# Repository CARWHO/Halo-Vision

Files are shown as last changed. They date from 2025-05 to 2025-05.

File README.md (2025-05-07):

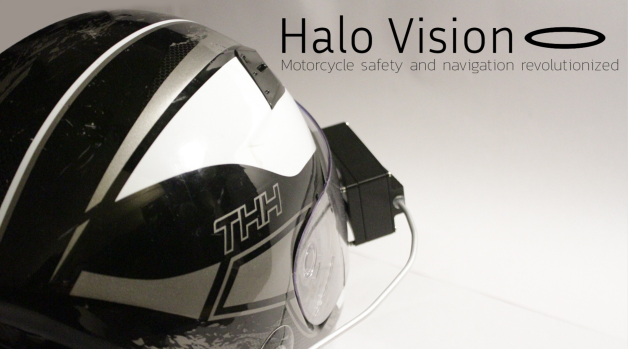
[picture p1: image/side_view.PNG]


# Halo Vision

**Open-Source Heads-Up Display for Motorcycle Safety**

Halo Vision is a helmet-mounted HUD that delivers turn-by-turn navigation and indicator notifications to motorcyclists, hands-free. Inspired by personal experiences, it evolved from a simple indicator broadcaster into a full display system with custom PCBs and a companion mobile app.

A full report—including detailed design motivations, hardware walkthrough, and CFD analysis—is available at:  
https://www.kahuhutton.com/work/halo-vision

---

## 🚀 What’s in this Repo

- **Schematics**    
  See [`/schematics/README.md`](schematics/schematics_readme.md).  
  Organized by module under `/schematics/`:
  - **Brain Module** and **Display Module** each have a `Project Outputs/` folder containing:  
    - **3D Views**  
    - **BOM (JLCPCB)**  
    - **Gerber**  
    - **JLCPCB Quotation**  
    - **Pick and Place**  
    - **Schematic** (PDF/PNG)  
    - **STEP** files  
    - **Source Files** (KiCad/Eagle project)  
    - **Original sketches**  
  These folders include all fabrication data and documentation for both the Brain and Display modules.    
  - ATmega32U2 pin mapping and net labels for easy modification  
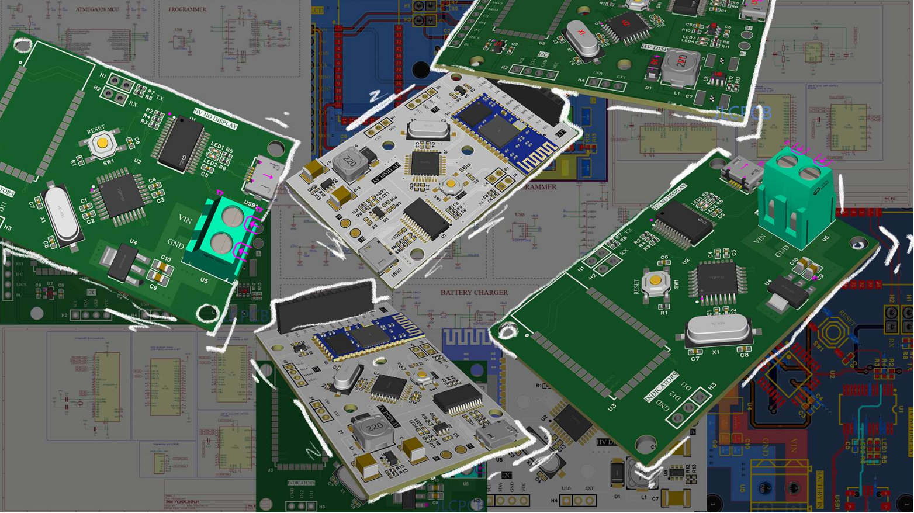
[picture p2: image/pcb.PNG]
  

- **Software**  
  See [`/software/README.md`](software/software_readme.md).  
  Organized under `/software/`:
  - **firmware/**
    - **brain_module/**  
      - `Makefile`  
      - `include/`  
        - `config.h`  
        - **hal/**: `gpio.h`, `uart.h`, `i2c.h`  
        - **modules/**: `gps.h`, `ble_uart.h`, `battery.h`  
      - `src/`  
        - `main.c`  
        - **hal/**: `gpio.c`, `uart.c`, `i2c.c`  
        - **drivers/**: `gps_driver.c`, `ble_uart.c`, `battery_monitor.c`  
        - **modules/**: `nav_logic.c`, `signal_detector.c`  
        - **util/**: `ring_buffer.c`, `logger.c`  
    - **display_module/**  
      - `Makefile`  
      - `include/`  
        - `config.h`  
        - **hal/**: `gpio.h`, `spi.h`, `uart.h`  
        - **modules/**: `display_driver.h`, `ble_rx.h`  
      - `src/`  
        - `main.c`  
        - **hal/**: `gpio.c`, `spi.c`, `uart.c`  
        - **drivers/**: `lcd_driver.c`, `ble_rx.c`  
        - **modules/**: `screen_updater.c`, `battery_status.c`  
        - **util/**: `ring_buffer.c`, `logger.c`  
  - **host_tools/**  
    - `flash_firmware.py`  
    - `diagnostics.py`  
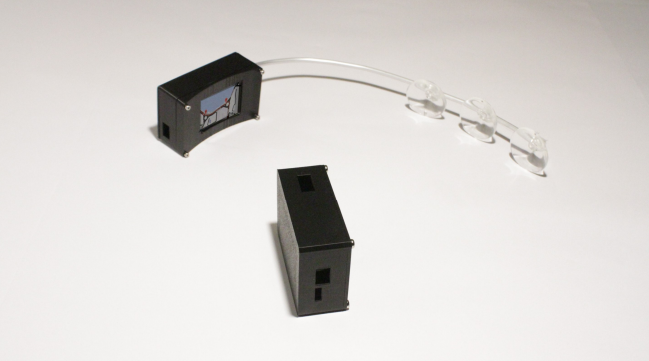
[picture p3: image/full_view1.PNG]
Software in action
  

## CAD Models & 3D Prints

All CAD assets live under the `/cad/` folder, organized by module. Each sub-folder includes a SolidWorks assembly (`.SLDASM`) plus its corresponding part files (`.SLDPRT`).  

**Module folders:**  
- `brainmodule/` – electronics housing assemblies and parts  
- `displaymodule/` – display housing assemblies and parts  
- `misc/` – hardware components (bolts, spacers, etc.)  

**Mount options:**  
- **HaloMount** – bracketed mount for helmet rim installation  
- **Direct Mount** – low-profile mount for direct shell attachment  

For print parameters, materials, and recommended hardware, see [`/cad/print_settings.md`](cad/print_settings.md).  
 
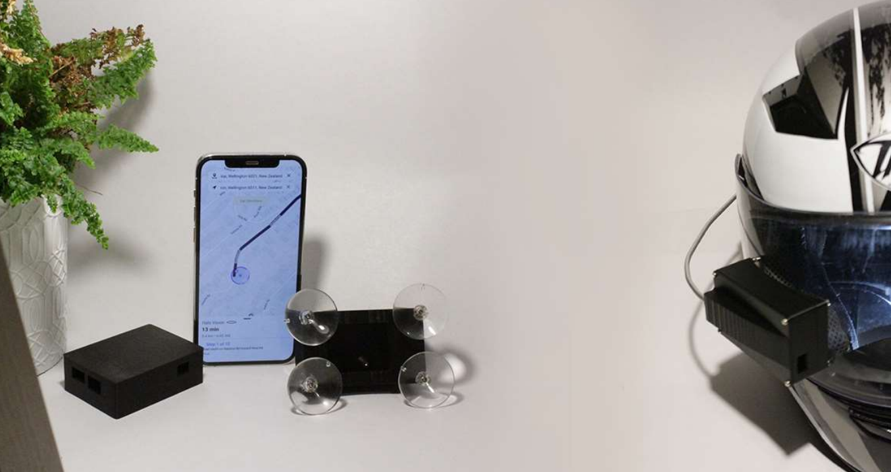
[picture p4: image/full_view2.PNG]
CAD models and mounts
  

- **Mobile App**  
  See [`/app/README.md`](app/README.md).  
  Joel Bannister’s Android navigator app threads GPS data to the HUD over Bluetooth:  
  https://github.com/1ceseismic/android_mapbox_lcd_navigator  
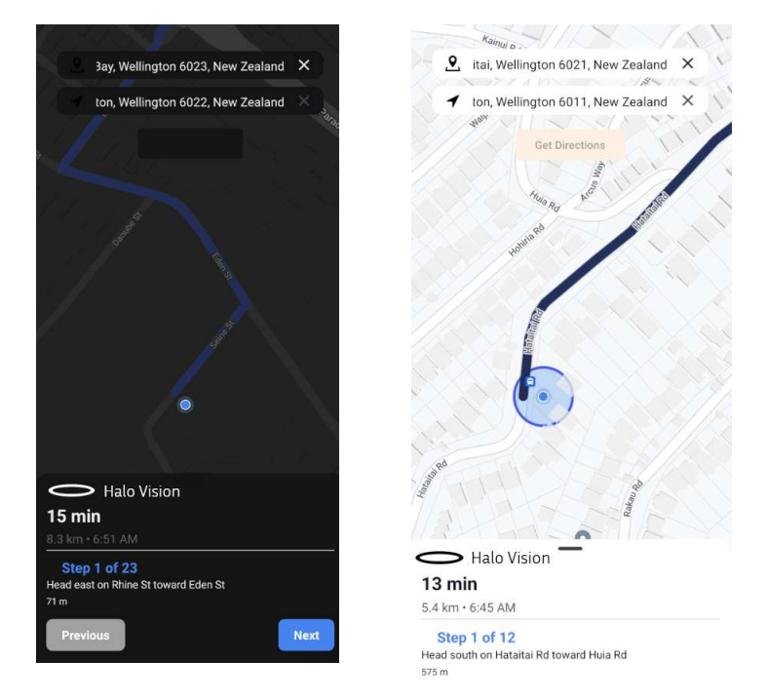
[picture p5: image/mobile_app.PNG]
Mobile App
  

---

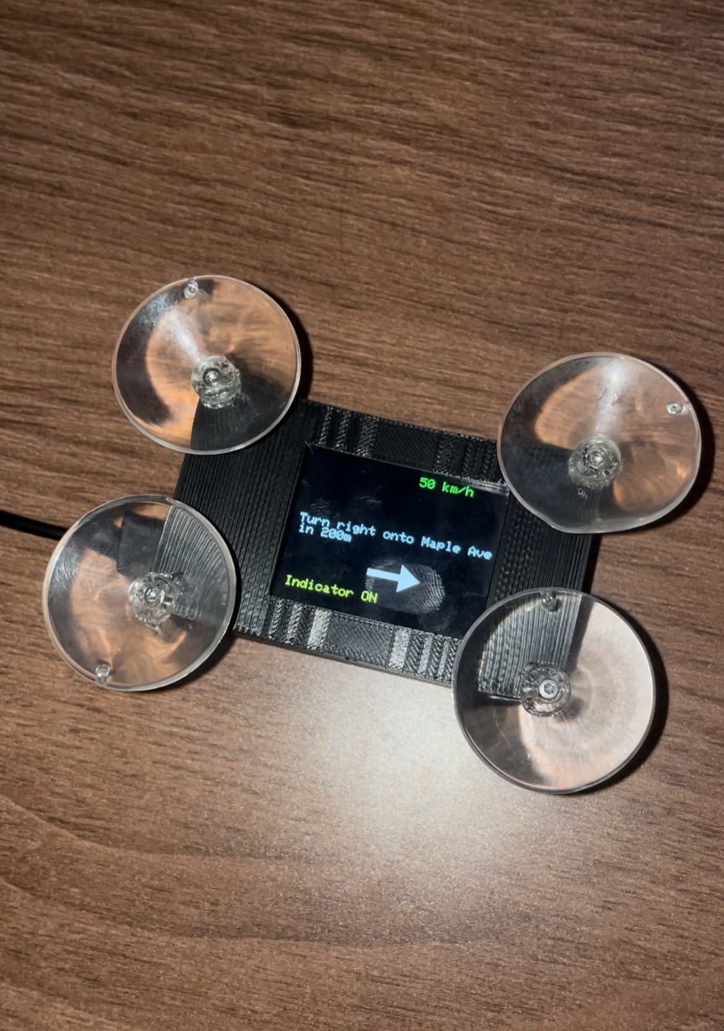
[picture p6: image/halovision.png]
Halo Vision Demo
  
## 🏁 Getting Started

Follow these steps to take your Halo Vision from GitHub to helmet-mounted HUD:

### 1. Clone this repo
```bash
git clone https://github.com/YourUsername/HaloVision.git
cd HaloVision
```

### 2. Order PCBs
- Open `/schematics/brain_module/Project Outputs/BOM (JLCPCB)/BOM.csv` and `/schematics/display_module/Project Outputs/BOM (JLCPCB)/BOM.csv`
- Upload both CSVs to JLCPCB (or your favorite board house) to fabricate the Brain and Display modules

### 3. 3D-print mounts & housings
- Choose a mount style (HaloMount, Direct Mount, etc.) in `/cad/`
- Follow `/cad/print_settings.md` for filament type, layer height, infill, and recommended screws

### 4. Build & flash firmware

**Brain Module:**
```bash
cd software/firmware/brain_module
make all
make flash
```

**Display Module:**
```bash
cd ../../display_module
make all
make flash
```

### 5. Install the mobile app
```bash
git clone https://github.com/1ceseismic/android_mapbox_lcd_navigator.git
```
Import into Android Studio, configure your Mapbox token, then build & install the APK on your device.

### 6. Assemble & power up
- Populate each PCB with the ordered components and solder per the assembly drawings
- Mount the PCBs in your 3D-printed housings and secure with the recommended screws
- Connect a Li-Po battery to each module's power header

### 7. Pair & test
- On your phone, open the installed app and pair to the HaloVisionHUD (PIN: 1234)
- Turn on the Brain Module (bike) and Display Module (helmet)
- Verify GPS lock, turn-signal detection, and live HUD updates before your next ride

---

Now you're ready to ride with Halo Vision. Enjoy hands-free navigation and stay safe!

📄 License
Distributed under the MIT License. See LICENSE for details.

Email me for further edits: kahu@kora.ac

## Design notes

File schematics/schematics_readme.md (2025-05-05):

# Schematics Overview

This document explains the functional blocks of the schematic diagrams for both the **Brain Module** (bike-mounted) and the **Display Module** (helmet-mounted).

---

## Brain Module Schematic

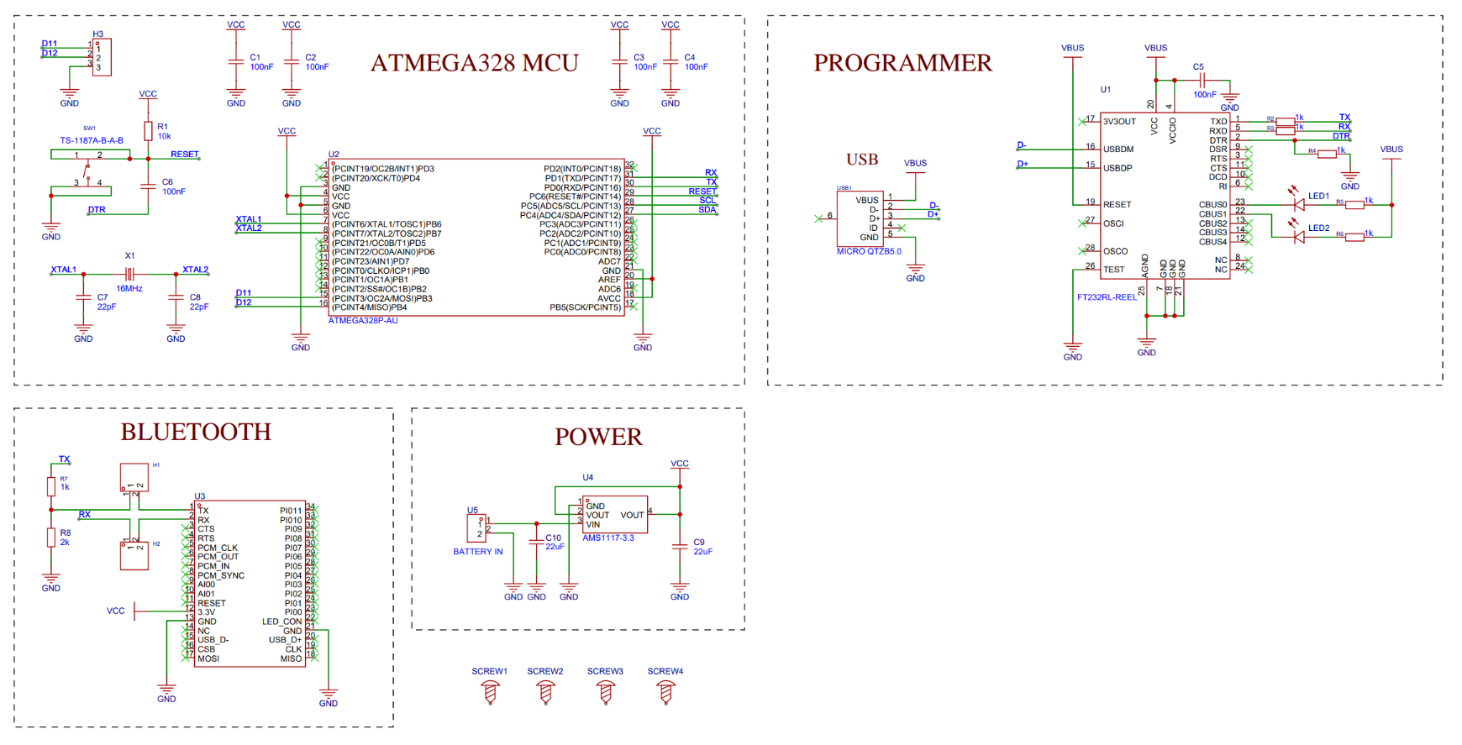
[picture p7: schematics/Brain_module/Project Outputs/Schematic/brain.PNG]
Brain Module Schematic


1. **ATmega328 MCU**  
   - **U2**: ATMEGA328P-AU microcontroller  
   - **Clock**: 16 MHz crystal (X1) with load caps C7/C8  
   - **Decoupling**: C1–C4 (100 nF) on VCC/AVCC  
   - **Reset circuit**: R1 (10 kΩ pull-up) + C6 (100 nF), DTR line via SW1 for auto-reset  

2. **Programmer Interface**  
   - **U1**: FT232RL USB-to-UART bridge  
   - **Connector**: MICRO QTZB5.0 (VBUS, D+, D–, ID, GND)  
   - **Signals**: TXD/RXD ↔ MCU PD0/PD1, DTR ↔ reset  
   - **Indicators**: LED1/LED2 with R5/R6 (1 kΩ) for TX/RX activity  

3. **Bluetooth Interface**  
   - **U3**: Bluetooth module (PI0xx)  
   - **Level shifting**: R7 (1 kΩ) on TX, R8 (2 kΩ) on RX  
   - **Connections**: TX/RX, CTS/RTS to MCU; powered from 3.3 V rail  

4. **Power Regulation**  
   - **U5**: AMS1117-3.3 linear regulator  
   - **Input cap**: C10 (22 µF), **Output cap**: C9 (22 µF)  
   - **Battery input**: VBAT → VIN  

5. **Mechanical Mounts**  
   - **Screw footprints**: SCREW1–SCREW4 for enclosure attachment  

---

## Display Module Schematic

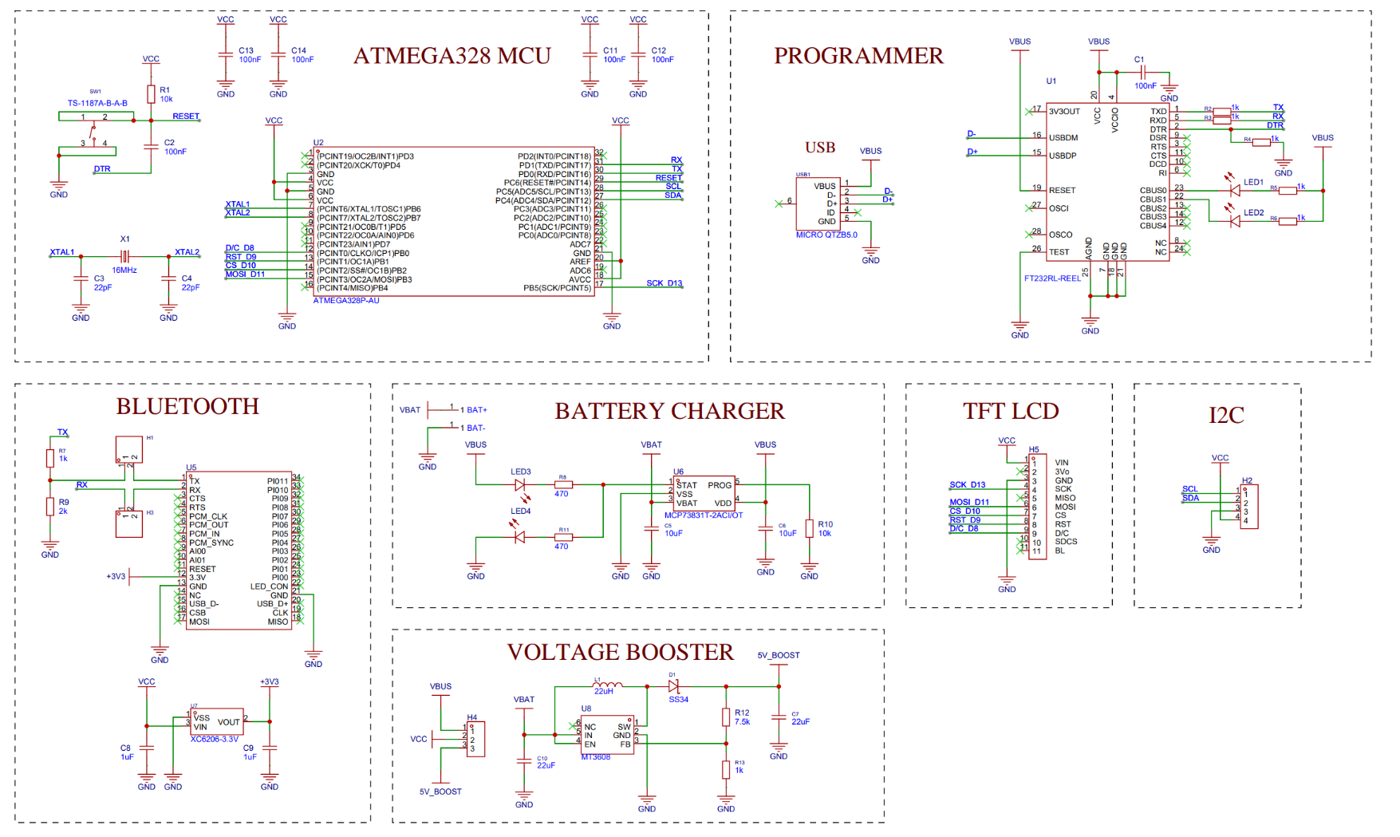
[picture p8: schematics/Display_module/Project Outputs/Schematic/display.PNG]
Display Module Schematic


1. **ATmega328 MCU**  
   - **U2**: ATMEGA328P-AU, identical clock & reset circuitry to Brain Module  

2. **Programmer Interface**  
   - **U1**: FT232RL, same USB-to-UART connections for firmware flashing  

3. **Bluetooth Receiver**  
   - **U5**: Bluetooth module wired for BLE RX only  

4. **Battery Charger**  
   - **U6**: MCP73831 Li-ion charger  
   - **Status LEDs**: LED3/LED4 with R8/R11 (470 Ω)  
   - **Input**: VBUS, **Output**: VBAT  

5. **TFT LCD Interface**  
   - **H5 header**:  
     - SCK (D13), MOSI (D11), MISO, CS (D10)  
     - RST (D8), D/C, SDCS, BL (backlight)  

6. **I²C Expansion**  
   - **H2 header**: SCL, SDA for external sensors  

7. **Voltage Booster**  
   - **U8**: MT3608 boost converter  
   - **Feedback**: R12 (7.5 kΩ), R13 (1 kΩ) → 5V_BOOST  
   - **Input cap**: C10 (22 µF), **Output cap**: C7 (22 µF)  

---

**All source files** (`.kicad_sch`, `.kicad_pcb`), Gerbers, BOM, Pick-and-Place, and STEP exports live under each module’s **Project Outputs/** folder.

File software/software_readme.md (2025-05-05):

# Halo Vision Software

This directory contains the software components for the Halo Vision project.

## Firmware

The `firmware/` directory holds the embedded software for the two main hardware modules:

- **`firmware/brain_module/`**: Firmware for the main processing unit. This module handles GPS data parsing, navigation logic, sensor reading (turn signals, speed, battery), and BLE communication with the Display Module. It runs on an ATmega328P microcontroller.

- **`firmware/display_module/`**: Firmware for the helmet-mounted display unit. This module receives data from the Brain Module via BLE, manages the LCD display, monitors its own battery and charging status, and renders the user interface. It also runs on an ATmega328P microcontroller.

Each firmware directory contains:
    - `include/`: Header files (.h) defining interfaces and configurations.
    - `src/`: Source code files (.c) implementing the firmware logic, drivers, and HAL.
    - `Makefile`: Build script for compiling the firmware using `avr-gcc`.

## Host Tools

The `host_tools/` directory contains utility scripts for development and maintenance:

- **`flash_firmware.py`**: (Placeholder) Script for flashing compiled firmware onto the microcontrollers.
- **`diagnostics.py`**: (Placeholder) Script for running diagnostics or communicating with the modules for debugging.

## Building Firmware

Navigate to either the `firmware/brain_module` or `firmware/display_module` directory and use the provided `Makefile`. Requires the `avr-gcc` toolchain and `avrdude` (for flashing).

```bash
# Example for Brain Module
cd firmware/brain_module
make all  # Compile the firmware
make flash # Flash the firmware (requires programmer configuration in Makefile)
make clean # Remove build artifacts
```

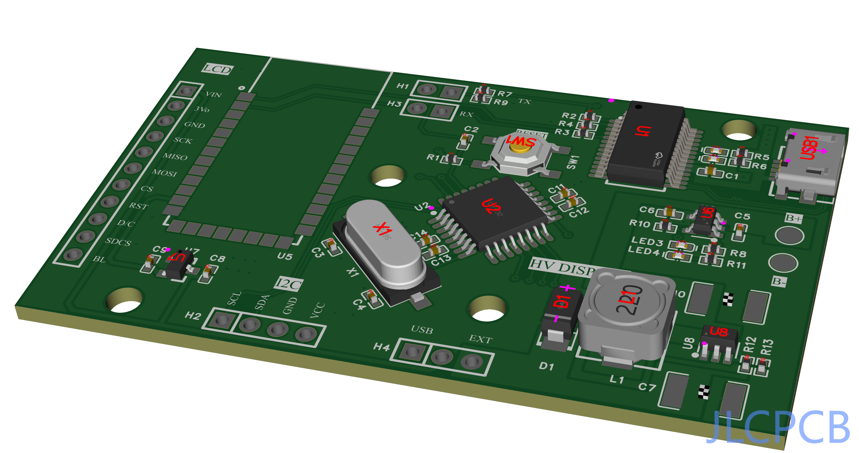
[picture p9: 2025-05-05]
schematics/Display_module/Project Outputs/3D Views/capture-2024-06-08T05_45_36.513Z.png

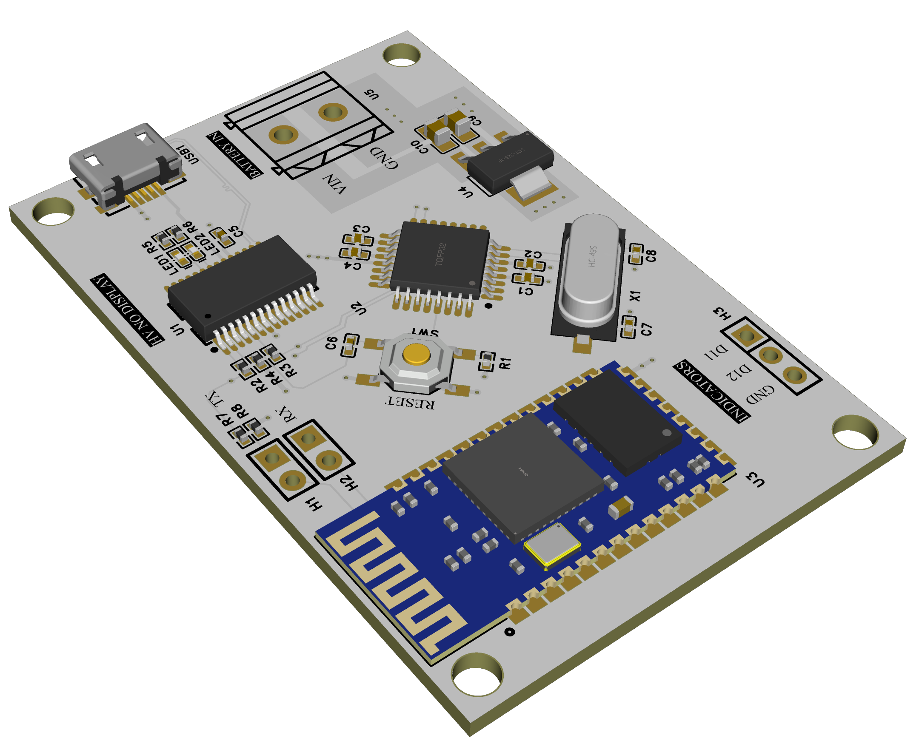
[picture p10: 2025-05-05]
schematics/Brain_module/Project Outputs/3D View/3D_PCB_2024-06-09_S3.png

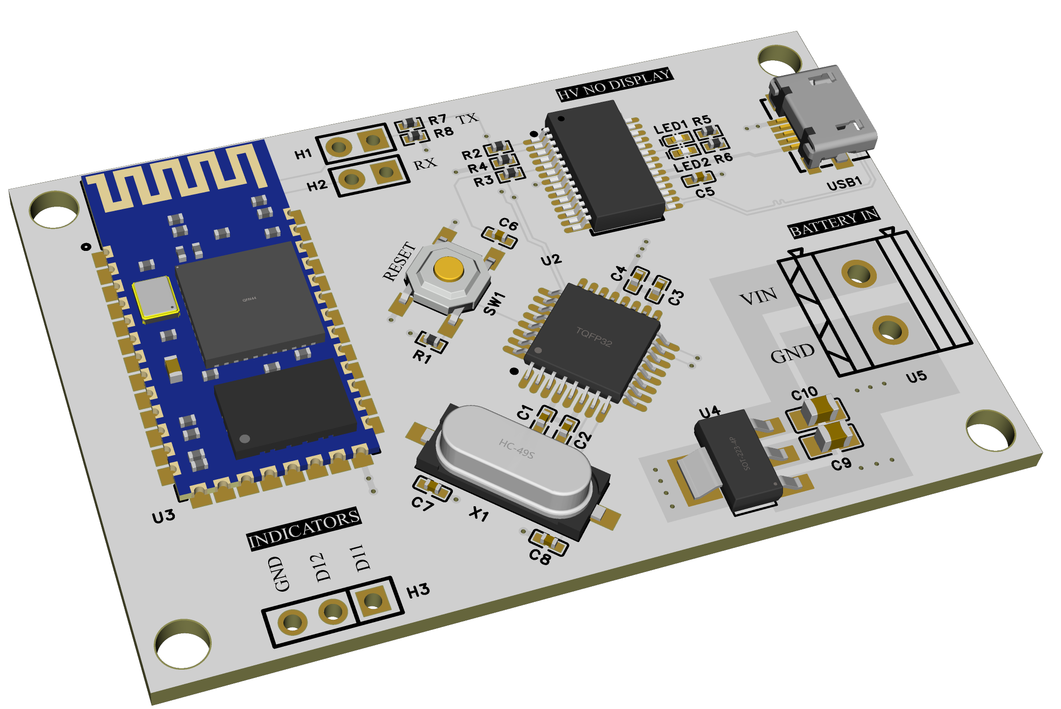
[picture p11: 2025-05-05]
schematics/Brain_module/Project Outputs/3D View/3D_PCB_2024-06-09_S1.png

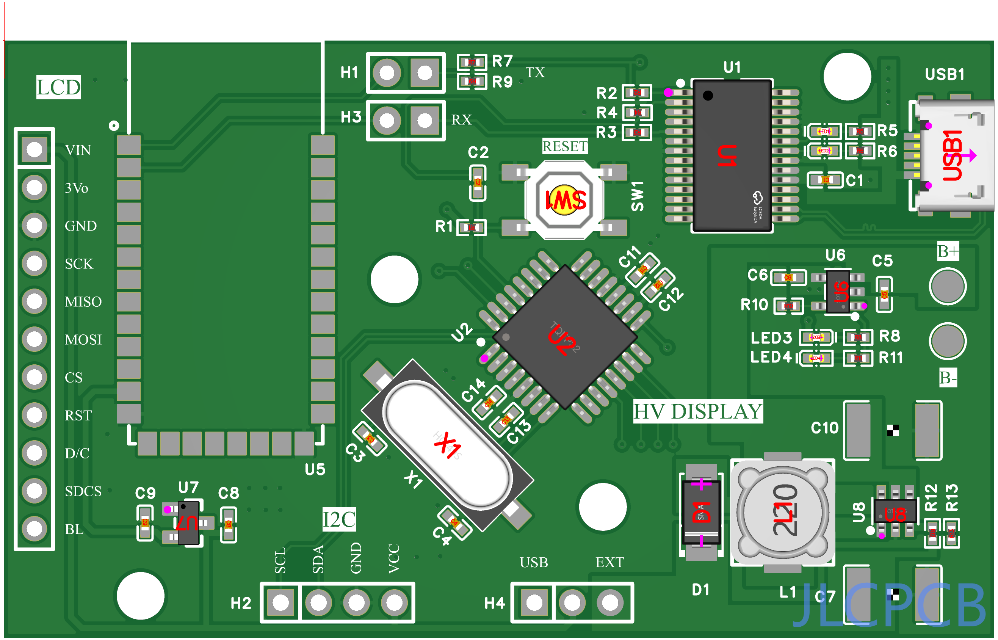
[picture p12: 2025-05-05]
schematics/Display_module/Project Outputs/3D Views/capture-2024-06-08T05_45_18.859Z.png

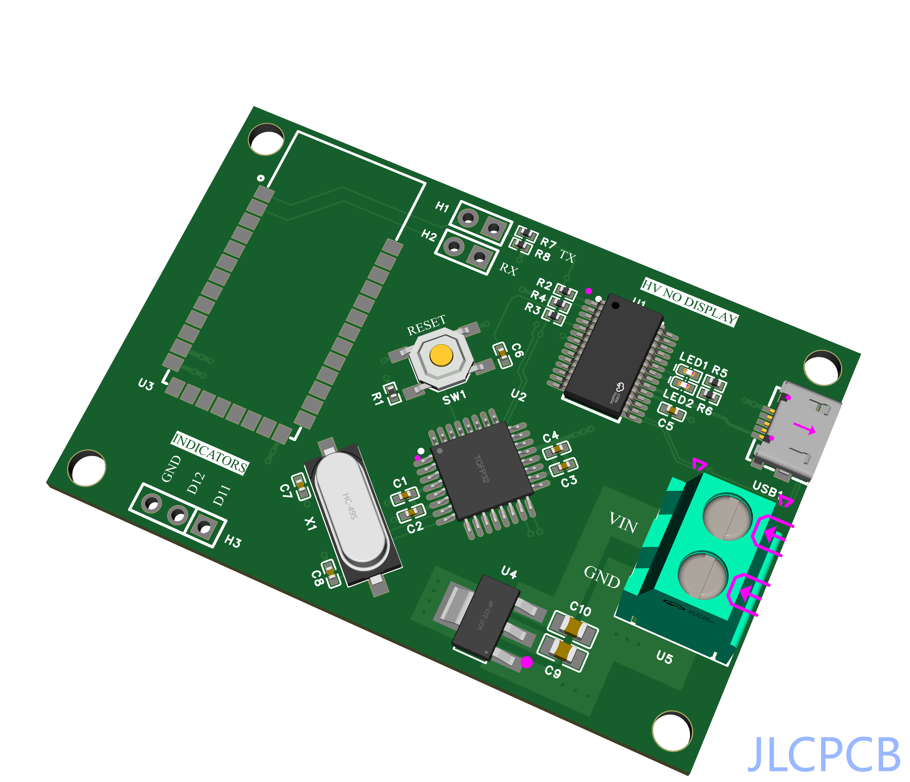
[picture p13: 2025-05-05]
schematics/Brain_module/Project Outputs/3D View/capture-2024-06-09T12_22_35.269Z.png

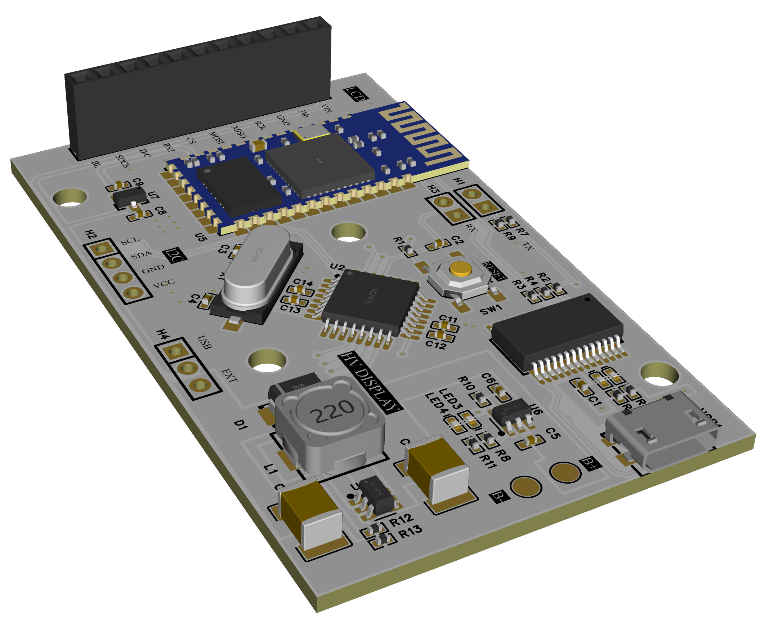
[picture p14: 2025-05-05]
schematics/Display_module/Project Outputs/3D Views/3D_PCB_2024-06-08_S2.png

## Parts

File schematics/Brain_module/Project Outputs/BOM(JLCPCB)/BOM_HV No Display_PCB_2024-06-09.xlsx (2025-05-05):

No. | Quantity | Comment | Designator | Footprint | Value | Manufacturer Part | Manufacturer | Supplier Part | Supplier
1 | 6 | 100nF | C1,C2,C3,C4,C5,C6 | C0402 | 100nF | CL05B104KB54PNC | SAMSUNG(三星) | C307331 | LCSC
2 | 2 | 22pF | C7,C8 | C0402 | 22pF | 0402CG220J500NT | FH(风华) | C1555 | LCSC
3 | 2 | 22uF | C9,C10 | C0805 | 22uF | CL21A226MAQNNNE | SAMSUNG(三星) | C45783 | LCSC
6 | 2 | TJ-S1005SW4TGLC2R-A5 | LED1,LED2 | LED0402-RD |  | TJ-S1005SW4TGLC2R-A5 | TOGIALED(统佳) | C273598 | LCSC
7 | 1 | 10kΩ | R1 | R0402 | 10kΩ | 0402WGF1002TCE | UNI-ROYAL(厚声) | C25744 | LCSC
8 | 6 | 1kΩ | R2,R3,R4,R5,R6,R7 | R0402 | 1kΩ | 0402WGF1001TCE | UNI-ROYAL(厚声) | C11702 | LCSC
9 | 1 | 2kΩ | R8 | R0402 | 2kΩ | 0402WGF2001TCE | UNI-ROYAL(厚声) | C4109 | LCSC
11 | 1 | TS-1187A-B-A-B | SW1 | SW-SMD_4P-L5.1-W5.1-P3.70-LS6.5-TL-2 |  | TS-1187A-B-A-B | XKB Connectivity(中国星坤) | C318884 | LCSC
12 | 1 | FT232RL-REEL | U1 | SSOP-28_L10.2-W5.3-P0.65-LS7.8-BL |  | FT232RL-REEL | FTDI(飞特帝亚) | C8690 | LCSC
13 | 1 | ATMEGA328P-AU | U2 | TQFP-32_L7.0-W7.0-P0.80-LS9.0-BL |  | ATMEGA328P-AU | MICROCHIP(美国微芯) | C14877 | LCSC
14 | 1 | {ManufacturerPart!} | U3 | BULETM-SMD_HC-05 |  | HC-05 |  | C9900001063 | LCSC
15 | 1 | AMS1117-3.3 | U4 | SOT-223-3_L6.5-W3.4-P2.30-LS7.0-BR |  | AMS1117-3.3 | AMS | C6186 | LCSC
16 | 1 | BATTERY IN | U5 | CONN-TH_2P-P5.08_DB128L-5.08-2P |  | BATTERY IN | DORABO(地博电气) | C395868 | LCSC
17 | 1 | MICRO QTZB5.0 | USB1 | MICRO-USB-SMD_MICRO-QTZB5.0 |  | MICRO QTZB5.0 | SHOU HAN(首韩) | C2681556 | LCSC
18 | 1 | 16MHz | X1 | HC-49S_L11.4-W4.8 | 16MHz | TAXM16M2GLFBET2T | YJX(雅晶鑫) | C111377 | LCSC

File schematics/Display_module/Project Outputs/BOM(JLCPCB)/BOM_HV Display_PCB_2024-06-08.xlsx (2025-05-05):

No. | Quantity | Comment | Designator | Footprint | Value | Manufacturer Part | Manufacturer | Supplier Part | Supplier
1 | 6 | 100nF | C1,C2,C11,C12,C13,C14 | C0402 | 100nF | CL05B104KB54PNC | SAMSUNG(三星) | C307331 | LCSC
2 | 2 | 22pF | C3,C4 | C0402 | 22pF | 0402CG220J500NT | FH(风华) | C1555 | LCSC
3 | 2 | 10uF | C5,C6 | C0402 | 10uF | CL05A106MQ5NUNC | SAMSUNG(三星) | C15525 | LCSC
4 | 2 | 22uF | C7,C10 | C1812 | 22uF | 1812X226K250NT | FH(风华) | C5189846 | LCSC
5 | 2 | 1uF | C8,C9 | C0402 | 1uF | CL05A105KA5NQNC | SAMSUNG(三星) | C52923 | LCSC
6 | 1 | SS34 | D1 | SMA_L4.3-W2.6-LS5.2-RD |  | SS34 | MDD | C8678 | LCSC
11 | 1 | 22uH | L1 | IND-SMD_L7.0-W6.8 | 22uH | SMRH74-220MT | SXN(顺翔诺) | C27442 | LCSC
12 | 3 | TJ-S1005SW4TGLC2R-A5 | LED1,LED2,LED3 | LED0402-RD |  | TJ-S1005SW4TGLC2R-A5 | TOGIALED(统佳) | C273598 | LCSC
13 | 1 | TJ-S1005SW4TGLC7K-A5 | LED4 | LED0402-RD_GREEN |  | TJ-S1005SW4TGLC7K-A5 | TOGIALED(统佳) | C273601 | LCSC
14 | 2 | 10kΩ | R1,R10 | R0402 | 10kΩ | 0402WGF1002TCE | UNI-ROYAL(厚声) | C25744 | LCSC
15 | 7 | 1kΩ | R2,R3,R4,R5,R6,R7,R13 | R0402 | 1kΩ | 0402WGF1001TCE | UNI-ROYAL(厚声) | C11702 | LCSC
16 | 2 | 470Ω | R8,R11 | R0402 | 470Ω | 0402WGF4700TCE | UNI-ROYAL(厚声) | C25117 | LCSC
17 | 1 | 2kΩ | R9 | R0402 | 2kΩ | 0402WGF2001TCE | UNI-ROYAL(厚声) | C4109 | LCSC
18 | 1 | 7.5kΩ | R12 | R0402 | 7.5kΩ | WR04X7501FTL | Walsin(华新科) | C168247 | LCSC
19 | 1 | TS-1187A-B-A-B | SW1 | SW-SMD_4P-L5.1-W5.1-P3.70-LS6.5-TL-2 |  | TS-1187A-B-A-B | XKB Connectivity(中国星坤) | C318884 | LCSC
20 | 1 | FT232RL-REEL | U1 | SSOP-28_L10.2-W5.3-P0.65-LS7.8-BL |  | FT232RL-REEL | FTDI(飞特帝亚) | C8690 | LCSC
21 | 1 | ATMEGA328P-AU | U2 | TQFP-32_L7.0-W7.0-P0.80-LS9.0-BL |  | ATMEGA328P-AU | MICROCHIP(美国微芯) | C14877 | LCSC
24 | 1 | {ManufacturerPart!} | U5 | BULETM-SMD_HC-05 |  | HC-05 |  | C9900001063 | LCSC
25 | 1 | MCP73831T-2ACI/OT | U6 | SOT-23-5_L3.0-W1.7-P0.95-LS2.8-BL |  | MCP73831T-2ACI/OT | MICROCHIP(美国微芯) | C424093 | LCSC
26 | 1 | XC6206-3.3V | U7 | SSOT-3_L2.9-W1.6-P0.95-LS2.8-BR |  | XC6206-3.3V | YONGYUTAI(永裕泰) | C2891841 | LCSC
27 | 1 | MT3608 | U8 | SOT-23-6_L2.9-W1.6-P0.95-LS2.8-BL |  | MT3608 | 西安航天民芯 | C84817 | LCSC
28 | 1 | MICRO QTZB5.0 | USB1 | MICRO-USB-SMD_MICRO-QTZB5.0 |  | MICRO QTZB5.0 | SHOU HAN(首韩) | C2681556 | LCSC
29 | 1 | 16MHz | X1 | HC-49S_L11.4-W4.8 | 16MHz | TAXM16M2GLFBET2T | YJX(雅晶鑫) | C111377 | LCSC

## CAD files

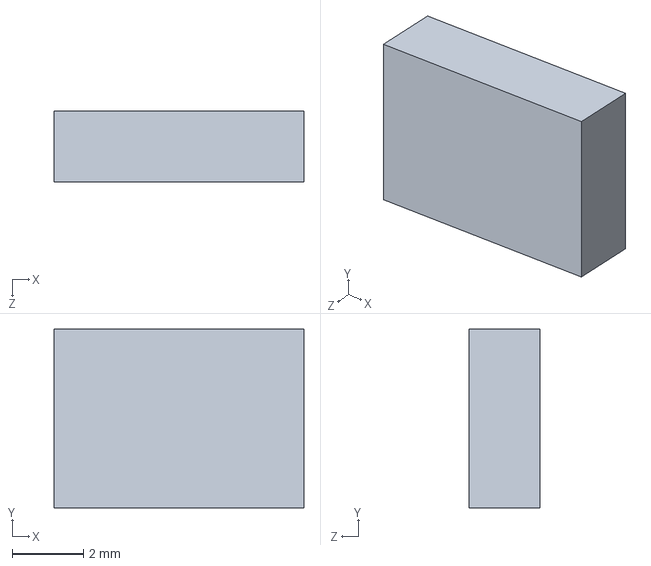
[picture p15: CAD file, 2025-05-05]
cad/brainmodule/USB_connector.SLDPRT
7.00 x 5.00 x 2.00 mm

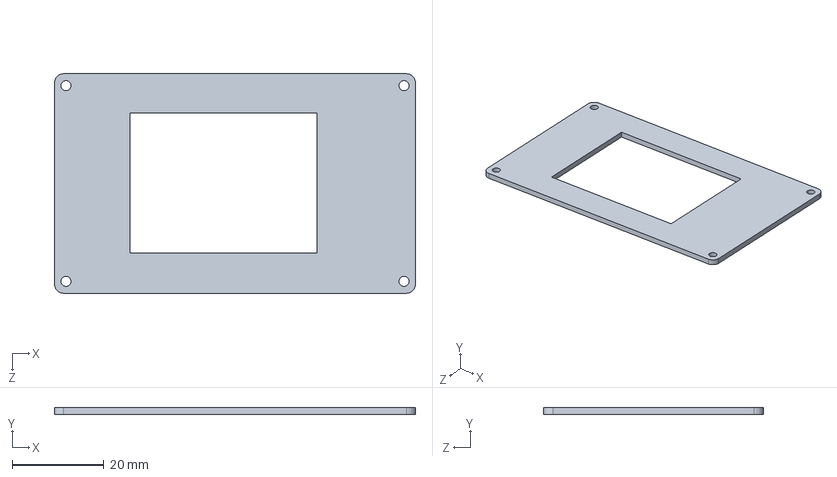
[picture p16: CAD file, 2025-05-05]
cad/displaymodule/Shell_2_LID.SLDPRT
78.9 x 1.50 x 48.0 mm

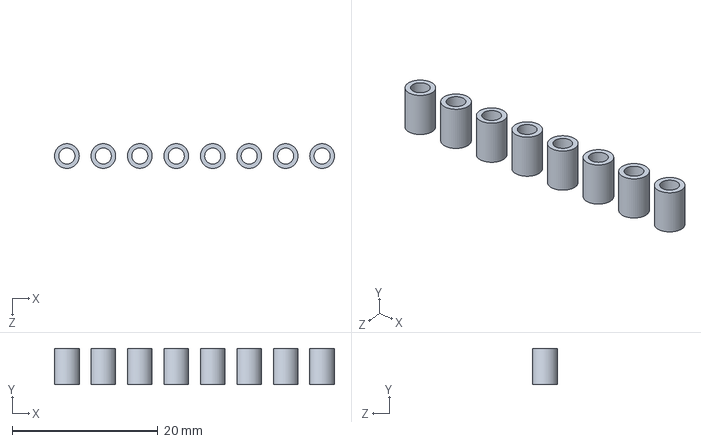
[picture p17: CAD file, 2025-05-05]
cad/misc/Shell_spacers.SLDPRT
38.4 x 5.00 x 3.41 mm

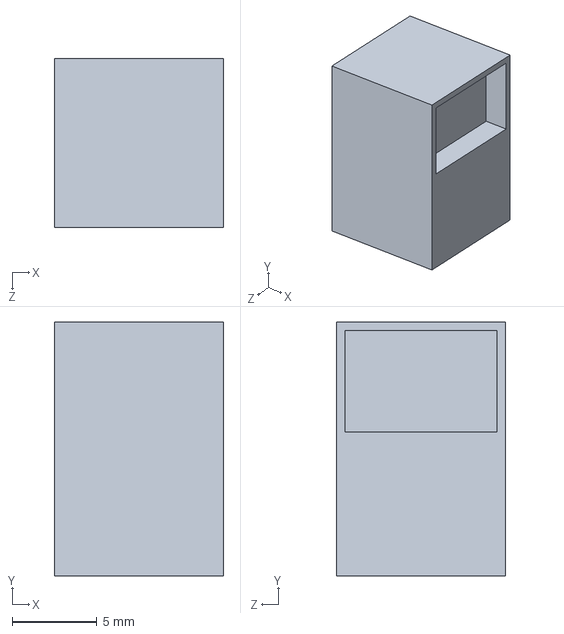
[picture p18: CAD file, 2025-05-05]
cad/brainmodule/PHE_connector.SLDPRT
10.0 x 15.0 x 10.0 mm

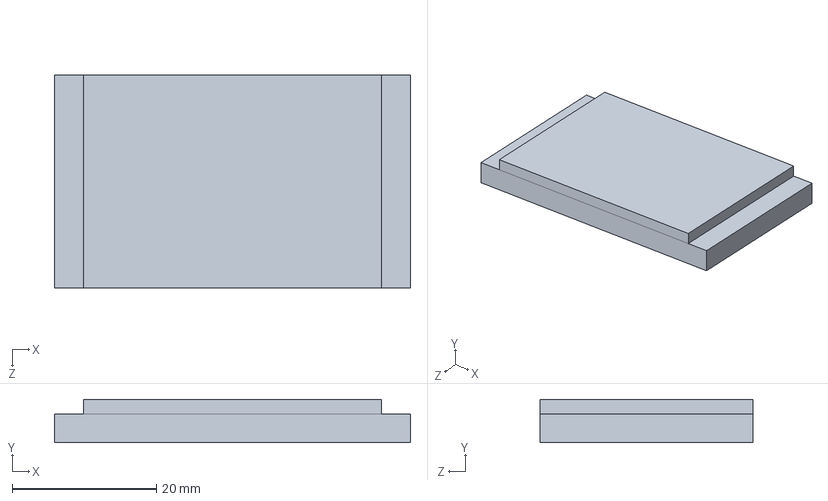
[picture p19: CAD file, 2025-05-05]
cad/displaymodule/TFT_DISPLAY.SLDPRT
49.3 x 6.00 x 29.5 mm

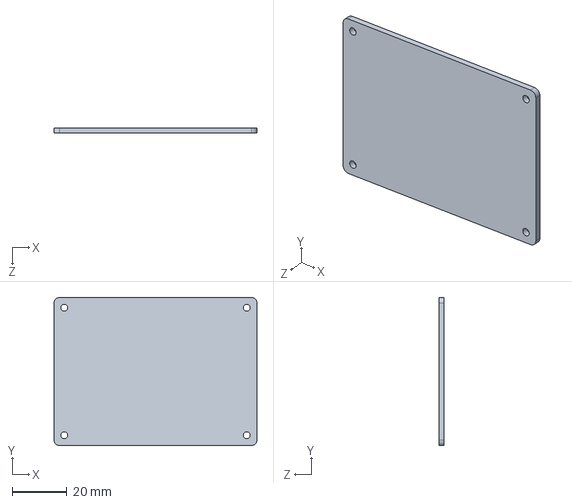
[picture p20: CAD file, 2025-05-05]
cad/brainmodule/Shell_2_LID.SLDPRT
74.0 x 54.0 x 2.00 mm

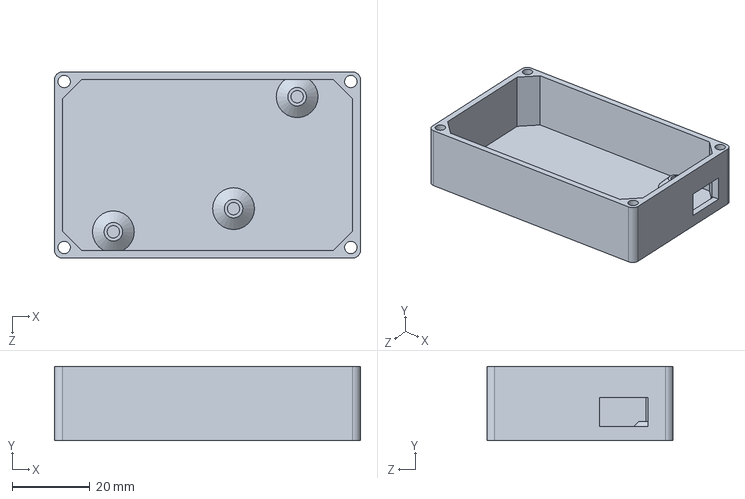
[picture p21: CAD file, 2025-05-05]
cad/displaymodule/Shell_1_DISP.SLDPRT
78.9 x 19.1 x 48.0 mm

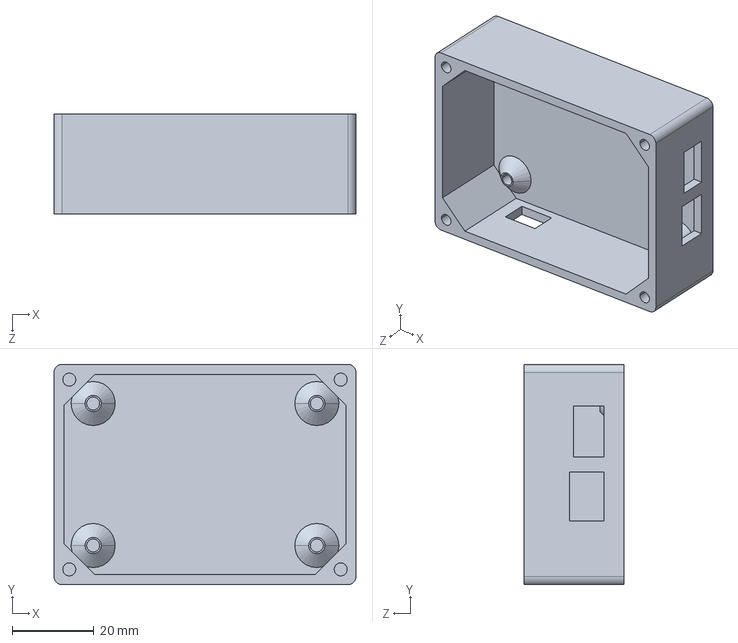
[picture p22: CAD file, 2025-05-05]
cad/brainmodule/Shell_1_NONDISP_adjustedport.SLDPRT
74.0 x 54.0 x 24.5 mm

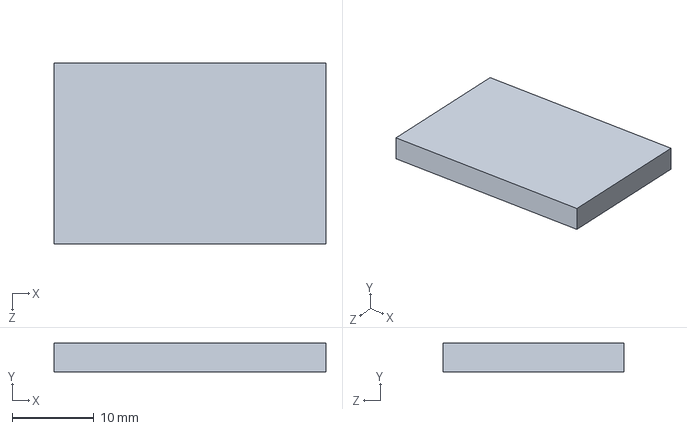
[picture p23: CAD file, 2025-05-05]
cad/displaymodule/LIPO_BATTERY.SLDPRT
33.3 x 3.50 x 22.2 mm

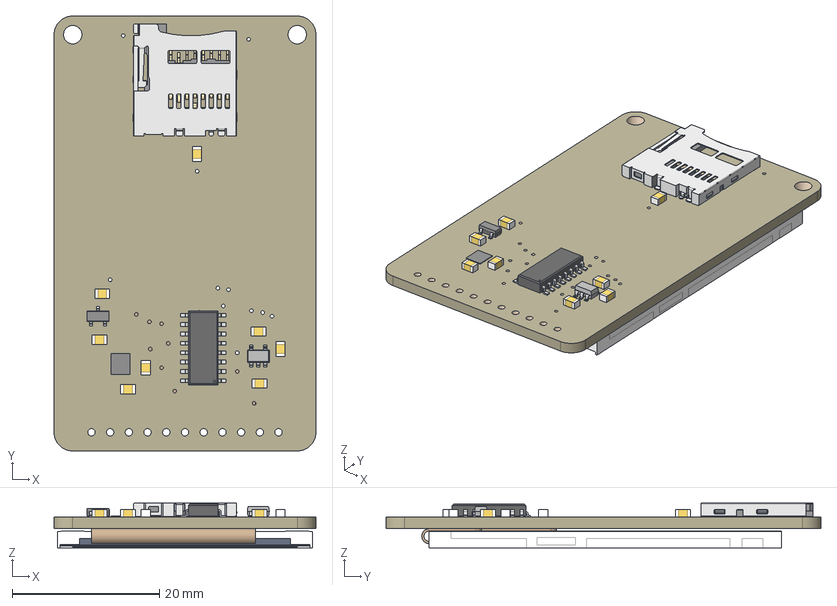
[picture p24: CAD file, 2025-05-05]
cad/displaymodule/4311 2in TFT IPS Display.step
35.6 x 59.1 x 6.08 mm
Board
10K x 8
AP2112K-3.3
74HC4050D
MICROSD
BSS138
DISP_LCD_GENERIC_SPI_2.0IN_240X320
APX803-SAG

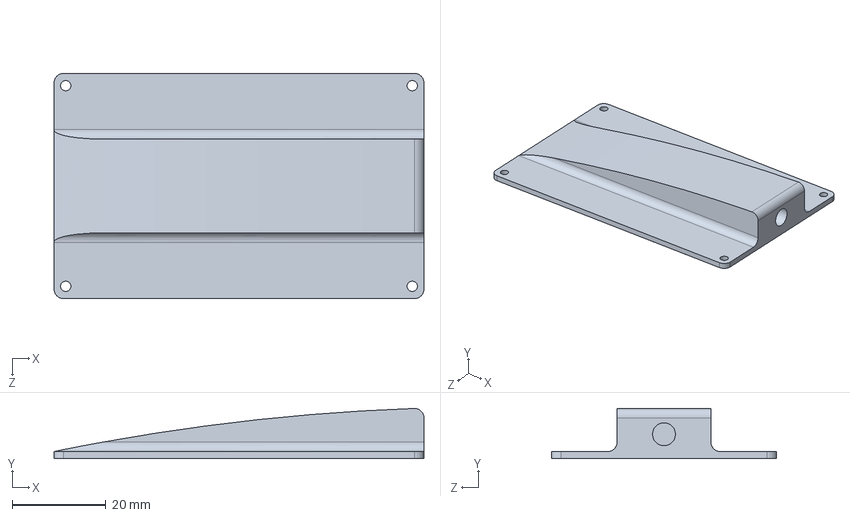
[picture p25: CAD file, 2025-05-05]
cad/displaymodule/Shell_3_HaloMount.SLDPRT
78.9 x 10.7 x 48.0 mm

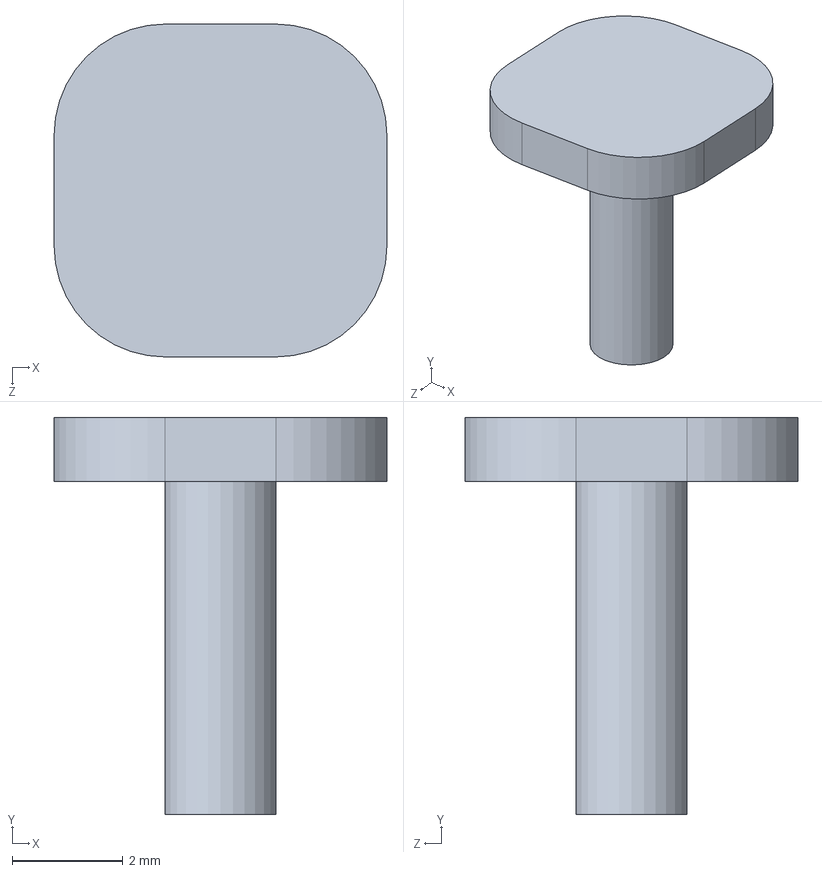
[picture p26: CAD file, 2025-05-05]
cad/misc/bolt_test_6mm.SLDPRT
6.00 x 7.16 x 6.00 mm

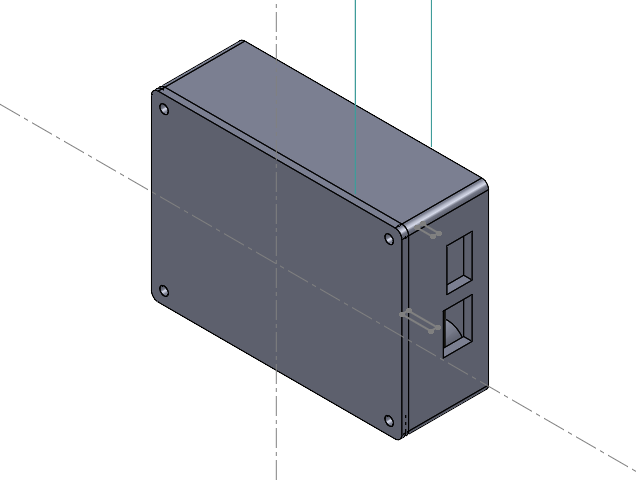
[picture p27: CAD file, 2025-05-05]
cad/brainmodule/PCB_CASING_ASSEM.SLDASM
SOLID.step x 8
SOLID-0.step x 8
COMPOUND.step
COMPOUND-1.step
COMPOUND-2.step x 2
COMPOUND-3.step
MICRO-USB-SMD_MICRO-QTZB5.0.step
C0805.step x 2
SOT-223-3_L6.5-W3.4-P2.30-LS7.0-BR.step
TQFP-32_L7.0-W7.0-P0.80-LS9.0-BL.step
BULETM-SMD_HC-05.step
Board.step
PHE_connector
USB_connector
Shell_2_LID

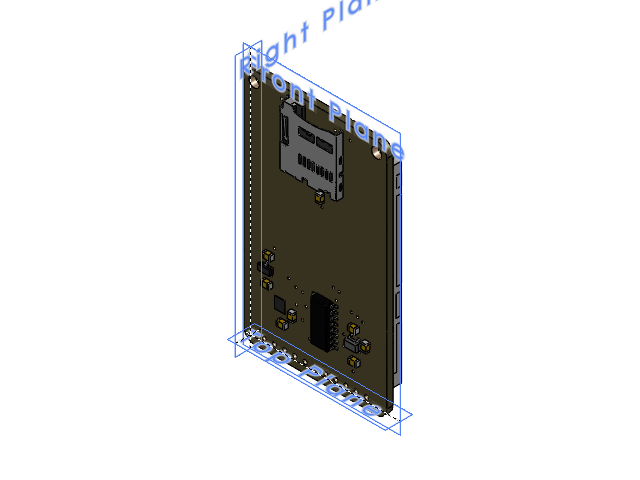
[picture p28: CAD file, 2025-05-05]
cad/displaymodule/4311 2in TFT IPS Display_NEW.SLDASM
Board_1.step
10K.step x 8
AP2112K-3.3.step
74HC4050D.step
MICROSD.step
BSS138.step
DISP_LCD_GENERIC_SPI_2.0IN_240X320.step
APX803-SAG.step

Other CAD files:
cad/brainmodule/Shell_1.SLDPRT

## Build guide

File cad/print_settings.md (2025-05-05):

# 3D Print Settings & Hardware

This document summarizes recommended print parameters, materials, and fasteners for all `/cad/` modules.

---

## 1. Materials & Filament

| Component | Filament Type | Color | Notes |
| --- | --- | --- | --- |
| Electronics Housing (brainmodule) | PETG | Black/Gray | Good chemical resistance |
| Display Housing (displaymodule) | PLA | White | Easy printability, aesthetic |
| Mount Brackets (HaloMount & Direct Mount) | PETG | Black | Strong and heat-tolerant |
| Hardware (misc) | PLA or PETG | -- | Nuts/spacers printed in PETG for strength |

---

## 2. Printer Settings

| Parameter | Value | Notes |
| --- | --- | --- |
| Nozzle Diameter | 0.4 mm | |
| Layer Height | 0.2 mm | Balance strength & speed |
| Print Speed | 40–60 mm/s | Slower for fine details  |
| Infill | 20%–30% | Rectilinear or grid |
| Extrusion Temp | 200–220 °C (PLA)<br>230–250 °C (PETG) | Tune by filament brand |
| Bed Temp | 60 °C (PLA)<br>80 °C (PETG) | Use adhesive if needed |
| Cooling Fan | 100% (PLA)<br>50% (PETG) | Improves overhangs |
| Build Plate Adhesion | Brim or Raft | For small parts & mounts |

---

## 3. Fasteners & Hardware

| Part | Quantity | Hardware Type | Notes |
| --- | --- | --- | --- |
| M2 Screws | 20 | M2 × 6 mm steel | Use with printed spacers |
| M3 Screws | 8 | M3 × 10 mm steel | Secure display bracket |
| Spacers | 12 | 6 mm (printed PETG) | For PCB standoffs |
| Nuts | 20 | M2 hex nuts | Nylon-locked preferred |

> **Tip:** Pre-tap holes with a small drill bit for embedded screws, or print holes 0.1–0.2 mm undersized and thread-tap after printing.

---

## 4. General Notes

* Orient parts to minimize overhangs on critical faces.
* Use supports for internal cavities (e.g., inside housing shells).
* Perform a test fit of all fasteners before final assembly.
* Adjust slicer settings per printer calibration and filament brand.

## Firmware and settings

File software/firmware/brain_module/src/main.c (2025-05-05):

/**
 * @file main.c
 * @brief Main application entry point for the Halo Vision Brain Module.
 * Initializes hardware abstraction layers (HAL), application modules,
 * and runs the main processing loop.
 */

#include <stdint.h>
#include <stdbool.h>
#include <util/delay.h> // For basic delays if needed

// Include HAL headers
#include "hal/gpio.h"
#include "hal/uart.h"
#include "hal/i2c.h"
// #include "hal/timer.h" // Include if a timer HAL is used

// Include Module headers
#include "modules/gps.h"
#include "modules/ble_uart.h"
#include "modules/battery.h"
#include "modules/nav_logic.h"
#include "modules/signal.h"

// Include Utilities
#include "util/logger.h"
#include "util/ring_buffer.h" // May be used internally by HAL/modules
#include "config.h"          // System configuration constants

// --- Private Function Prototypes ---
static void hardware_init(void);
static void modules_init(void);
static void main_loop(void);
static void process_communication(void);
static void process_sensors(void);
static void run_logic_updates(void);

// --- Global Variables / State (Use Sparingly) ---
// Example: System tick or flags for periodic tasks
volatile uint32_t system_ticks_ms = 0; // Assume updated by a timer ISR

/**
 * @brief Main function - entry point of the application.
 */
int main(void) {
    // Initialize hardware peripherals first.
    hardware_init();

    // Initialize application modules.
    modules_init();

    log_info("---------------------------------");
    log_info("Halo Vision Brain Module Starting");
    log_info("---------------------------------");

    // Enter the main processing loop.
    main_loop();

    // This point should ideally never be reached.
    return 0;
}

/**
 * @brief Initializes core hardware peripherals using the HAL.
 */
static void hardware_init(void) {
    // Initialize GPIO pins for signals, sensors, etc.
    // Pins are defined in config.h
    hal_gpio_init(LEFT_SIGNAL_PIN, GPIO_MODE_INPUT_PULLUP);
    hal_gpio_init(RIGHT_SIGNAL_PIN, GPIO_MODE_INPUT_PULLUP);
    hal_gpio_init(SPEED_SENSOR_PIN, GPIO_MODE_INPUT_PULLUP); // Assuming pullup needed
    // Battery sense pin init is handled by battery_monitor_init -> hal_gpio_init

    // Initialize UART interfaces (GPS, BLE/Log)
    // Note: UART init for GPS/BLE is handled within their respective module inits.
    // Logger init handles its own UART.

    // Initialize I2C interface (if used by any sensors directly)
    hal_i2c_init(MAIN_I2C_ID, I2C_CLOCK_SPEED);

    // Initialize Timers (if used for periodic tasks, debouncing, etc.)
    // hal_timer_init(...);
    // hal_timer_start(...);

    // Enable global interrupts if required by HAL components (e.g., UART RX, Timers)
    // sei(); // Needs <avr/interrupt.h>

    log_debug("Hardware initialization complete.");
}

/**
 * @brief Initializes all application-level modules.
 */
static void modules_init(void) {
    // Logger needs to be initialized first if other modules log during init.
    logger_init();

    // Initialize remaining modules
    battery_monitor_init();
    gps_init();
    ble_uart_init();
    signal_detector_init();
    nav_logic_init();

    log_debug("Application modules initialization complete.");
}

/**
 * @brief Main application super-loop.
 * Continuously processes inputs, runs logic, and generates outputs.
 */
static void main_loop(void) {
    uint32_t last_status_update_ms = 0;
    uint32_t last_nav_update_ms = 0;

    while (1) {
        // Update system time (crude simulation if no timer ISR)
        // system_ticks_ms++;
        // _delay_ms(1); // Very basic delay if no timer

        // 1. Process Communication Interfaces (UARTs, I2C)
        process_communication();

        // 2. Process Sensor Inputs (GPIOs, ADC)
        process_sensors();

        // 3. Run Core Logic Updates (Navigation, State Machines)
        // Run periodically based on system time or flags set by ISRs/polling.
        uint32_t now = system_ticks_ms; // Use actual timer value if available
        if (now - last_nav_update_ms >= NAV_UPDATE_INTERVAL_MS) {
             run_logic_updates();
             last_nav_update_ms = now;
        }

        // 4. Send Periodic Status Updates via BLE
        if (now - last_status_update_ms >= BLE_STATUS_UPDATE_INTERVAL_MS) {
            if (ble_uart_is_connected()) {
                 uint16_t batt_mv = battery_monitor_get_voltage_mv();
                 signal_state_t sig_state = signal_detector_get_state();
                 float speed = gps_get_speed_kmh(); // Use latest speed from GPS/NavLogic
                 ble_uart_send_status_update(batt_mv, sig_state, (uint8_t)speed);
            }
             last_status_update_ms = now;
        }

        // 5. Optional: Enter low-power sleep mode if idle.
        // sleep_cpu();
    }
}

/**
 * @brief Handles processing of incoming data from communication interfaces.
 */
static void process_communication(void) {
    // Poll GPS UART for incoming NMEA characters
    while (hal_uart_data_available(GPS_UART_ID)) {
        int16_t data = hal_uart_get_char(GPS_UART_ID);
        if (data != -1) {
            gps_process_char((uint8_t)data);
        }
    }

    // Poll BLE UART for incoming commands or responses
    while (hal_uart_data_available(BLE_UART_ID)) {
         int16_t data = hal_uart_get_char(BLE_UART_ID);
        if (data != -1) {
            ble_uart_process_char((uint8_t)data);
            // Also pass to logger if echoing input is desired
            // log_char((char)data);
        }
    }

    // Handle I2C communication if needed (e.g., polling sensors)
}

/**
 * @brief Handles reading and processing of sensor inputs.
 */
static void process_sensors(void) {
    // Update turn signal detection logic (reads GPIOs, debounces)
    signal_detector_update();

    // Read battery voltage (reads ADC) - reading might happen within get_voltage_mv
    // battery_monitor_get_voltage_mv(); // Called periodically in main loop for status update

    // Read speed sensor (if separate from GPS, e.g., Hall effect)
    // speed_sensor_update(); // Would read GPIO/timer/interrupts
}

/**
 * @brief Executes core application logic updates.
 */
static void run_logic_updates(void) {
    // Update navigation logic based on latest GPS data and sensor inputs
    if (gps_is_data_available()) {
        gps_data_t gps_reading;
        if (gps_get_data(&gps_reading)) {
            nav_logic_set_gps_data(&gps_reading);
        } else {
            nav_logic_set_gps_data(NULL); // Indicate invalid fix
        }
    }
    // Pass other relevant sensor data to nav logic if needed
    // nav_logic_set_speed(...); // Speed might be set directly from GPS data
    nav_logic_set_signal_state(signal_detector_get_state());

    // Trigger navigation logic calculation/update
    nav_logic_update(); // This function now also sends the BLE nav update
}

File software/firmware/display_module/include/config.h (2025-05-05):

#ifndef DISPLAY_CONFIG_H
#define DISPLAY_CONFIG_H

/**
 * @file config.h
 * @brief Central configuration file for the Halo Vision Display Module firmware.
 */

#include <stdint.h>

// --- System Configuration ---
#define F_CPU 16000000UL // System clock frequency: 16 MHz (from schematic)

// --- Peripheral Configuration ---

// UART for BLE Communication (Hardware USART0)
#define BLE_UART_ID         UART_ID_0 // Maps to HW USART0
#define BLE_UART_BAUD       115200UL  // Baud rate matching Brain Module BLE
#define BLE_UART_RX_BUFFER_SIZE 128   // Buffer for incoming data from Brain Module
#define BLE_UART_TX_BUFFER_SIZE 32    // Buffer for outgoing acknowledgements (if any)

// SPI for LCD Communication (Hardware SPI)
#define LCD_SPI_ID          SPI_ID_0 // Maps to HW SPI
#define LCD_SPI_MODE        0        // SPI Mode (CPOL=0, CPHA=0 typical for LCDs)
#define LCD_SPI_CLOCK_SPEED 4000000UL // SPI Clock Speed (e.g., 4 MHz)

// I2C (Hardware TWI) - For potential external sensors via header
#define EXTERNAL_I2C_ID     I2C_ID_0 // Maps to HW TWI
#define I2C_CLOCK_SPEED     100000UL // 100 kHz standard I2C speed

// --- Pin Definitions (ATmega328P QFP32 package mapping - based on schematic) ---

// Port D Pins
#define UART0_RXD_PIN       PD0 // Pin 2 (QFP32) - BLE UART RX
#define UART0_TXD_PIN       PD1 // Pin 3 (QFP32) - BLE UART TX
// PD2, PD3, PD4 potentially available or used for I2C header?

// Port C Pins
#define BATT_CHG_STAT_PIN   PC0 // Pin 23 (QFP32) - MCP73831 Status Output (Input)
#define BATT_SENSE_PIN      PC1 // Pin 24 (QFP32) - Battery Voltage Sense (ADC1)
// PC4 (SDA), PC5 (SCL) used by I2C Header

// Port B Pins
#define LCD_CS_PIN          PB2 // Pin 16 (QFP32) - SPI Chip Select for LCD (Output, SS)
#define LCD_MOSI_PIN        PB3 // Pin 17 (QFP32) - SPI MOSI (Output)
#define LCD_MISO_PIN        PB4 // Pin 18 (QFP32) - SPI MISO (Input, if needed)
#define LCD_SCK_PIN         PB5 // Pin 19 (QFP32) - SPI Clock (Output)
#define LCD_DC_PIN          PB0 // Pin 14 (QFP32) - LCD Data/Command Select (Output)
#define LCD_RST_PIN         PB1 // Pin 15 (QFP32) - LCD Reset (Output)

// --- Module Configuration ---

// LCD Driver
#define LCD_WIDTH           128 // Example LCD width in pixels
#define LCD_HEIGHT          160 // Example LCD height in pixels
#define LCD_DEFAULT_BG_COLOR 0x0000 // Black background
#define LCD_DEFAULT_FG_COLOR 0xFFFF // White foreground

// Battery Status
#define BATTERY_ADC_VREF_MV 3300.0f  // ADC reference voltage (3.3V regulator)
#define BATTERY_ADC_MAX_VALUE 1023   // 10-bit ADC
// Voltage divider for battery sense (if used directly, schematic implies charger handles it)
// #define BATTERY_SENSE_R1_OHMS 10000.0f
// #define BATTERY_SENSE_R2_OHMS 10000.0f // Example 1:1 divider if Vbat <= Vref

// Screen Updater
#define SCREEN_UPDATE_INTERVAL_MS 100 // How often to refresh screen elements

// BLE Receiver Protocol
#define BLE_MSG_TERMINATOR '\n' // Character indicating end of message from Brain Module

// --- Feature Flags ---
#define ENABLE_LOGGING          1      // 1 to enable logging, 0 to disable
#define LOG_LEVEL               LOG_LEVEL_INFO // Default log level
#define LOG_UART_ID             BLE_UART_ID // Send logs over BLE UART
#define LOG_UART_BAUD           BLE_UART_BAUD

#endif // DISPLAY_CONFIG_H

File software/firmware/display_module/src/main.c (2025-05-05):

/**
 * @file main.c
 * @brief Main application entry point for the Halo Vision Display Module.
 */

#include <stdint.h>
#include <stdbool.h>
#include <util/delay.h>

// Include HAL headers
#include "hal/gpio.h"
#include "hal/uart.h"
#include "hal/spi.h"
// #include "hal/i2c.h" // Include if I2C is used
// #include "hal/timer.h"

// Include Module headers/drivers
#include "modules/display_driver.h"
#include "modules/ble_rx.h"
#include "modules/battery_status.h" // Assuming header exists
#include "modules/screen_updater.h" // Assuming header exists

// Include Utilities
#include "util/logger.h"
#include "util/ring_buffer.h"
#include "config.h"

// --- Private Function Prototypes ---
static void hardware_init(void);
static void modules_init(void);
static void main_loop(void);
static void process_ble_input(void);
static void update_system_status(void);

// --- Global Variables / State ---
volatile uint32_t system_ticks_ms = 0; // Assume updated by a timer ISR

/**
 * @brief Main function - entry point.
 */
int main(void) {
    hardware_init();
    modules_init();

    log_info("-----------------------------------");
    log_info("Halo Vision Display Module Starting");
    log_info("-----------------------------------");

    main_loop();

    return 0; // Should not be reached
}

/**
 * @brief Initializes core hardware peripherals.
 */
static void hardware_init(void) {
    // GPIOs for LCD control (CS, DC, RST) are initialized within display_init() -> hal_gpio_init()
    // GPIO for Battery Charger Status is initialized within battery_status_init() -> hal_gpio_init()

    // Initialize UART for BLE communication
    // Note: UART init is handled by logger_init() as it uses the same UART.
    // If separate UARTs were used, init BLE UART here:
    // hal_uart_init(BLE_UART_ID, BLE_UART_BAUD, 8, 1, 0);

    // Initialize SPI for LCD communication
    // Note: SPI init is handled by display_init() -> hal_spi_init()

    // Initialize I2C if needed for external sensors via header
    // hal_i2c_init(EXTERNAL_I2C_ID, I2C_CLOCK_SPEED);

    // Initialize Timers for periodic tasks
    // hal_timer_init(...);
    // hal_timer_start(...);

    // Enable global interrupts if needed
    // sei();

    log_debug("Hardware initialization complete.");
}

/**
 * @brief Initializes application modules.
 */
static void modules_init(void) {
    // Logger first
    logger_init();

    // Initialize drivers and modules
    display_init(); // Initializes LCD hardware (SPI, GPIOs)
    ble_rx_init();
    battery_status_init(); // Initializes battery monitoring (GPIO, ADC)
    screen_updater_init(); // Initializes UI state

    log_debug("Application modules initialization complete.");
}

/**
 * @brief Main application loop.
 */
static void main_loop(void) {
    uint32_t last_screen_update_ms = 0;
    uint32_t last_battery_update_ms = 0;

    while (1) {
        // Update system time (simulation)
        // system_ticks_ms++;
        // _delay_ms(1);

        // 1. Process incoming BLE data
        process_ble_input();

        // 2. Update system status (Battery) periodically
        uint32_t now = system_ticks_ms; // Use actual timer value
        if (now - last_battery_update_ms >= 1000) { // Update battery status every second
            update_system_status();
            last_battery_update_ms = now;
        }

        // 3. Update screen content periodically
        if (now - last_screen_update_ms >= SCREEN_UPDATE_INTERVAL_MS) {
            screen_updater_update(); // Checks for data changes and redraws if needed
            last_screen_update_ms = now;
        }

        // 4. Low power mode?
        // sleep_cpu();
    }
}

/**
 * @brief Processes incoming characters from the BLE UART.
 */
static void process_ble_input(void) {
    while (hal_uart_data_available(BLE_UART_ID)) {
        int16_t data = hal_uart_get_char(BLE_UART_ID);
        if (data != -1) {
            ble_rx_process_char((uint8_t)data); // Pass character to BLE receiver module
        }
    }
}

/**
 * @brief Updates status monitoring modules (e.g., battery).
 */
static void update_system_status(void) {
    battery_status_update(); // Read charger status, update level estimate
}

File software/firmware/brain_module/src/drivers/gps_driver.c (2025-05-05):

/**
 * @file gps_driver.c
 * @brief Driver for handling GPS communication and NMEA sentence parsing.
 * Interacts with the UART HAL to receive data and provides structured GPS info.
 *
 * This implementation focuses on parsing $GPRMC and $GPGGA sentences.
 */

#include "modules/gps.h" // Use the module header file name
#include "hal/uart.h"
#include "util/logger.h"
#include <string.h> // For strcmp, strlen, etc.
#include <stdlib.h> // For atof, atoi
#include <stdio.h>  // For sscanf (use with caution on embedded systems due to code size)

// --- Defines ---
#define NMEA_MAX_SENTENCE_LEN 82   // Maximum NMEA sentence length
#define NMEA_MAX_FIELDS 20         // Maximum number of comma-separated fields expected

// --- Internal State ---
static gps_data_t current_gps_data; // Holds the latest parsed data
static bool data_updated = false;   // Flag indicating new data is available
static bool data_valid_fix = false; // Flag indicating the current data represents a valid fix

// NMEA sentence buffer and parser state
static char nmea_buffer[NMEA_MAX_SENTENCE_LEN + 1];
static uint8_t nmea_buffer_index = 0;
static bool sentence_in_progress = false;

// --- NMEA Parsing Helper Functions ---

// Calculate NMEA checksum
static uint8_t nmea_calculate_checksum(const char *sentence) {
    uint8_t checksum = 0;
    // Checksum includes characters between '$' and '*'
    if (*sentence == '$') sentence++;
    while (*sentence && *sentence != '*') {
        checksum ^= *sentence++;
    }
    return checksum;
}

// Validate NMEA checksum
static bool nmea_validate_checksum(const char *sentence) {
    const char *checksum_str = strchr(sentence, '*');
    if (!checksum_str || strlen(checksum_str) < 3) {
        return false; // No '*' or checksum too short
    }
    uint8_t calculated_checksum = nmea_calculate_checksum(sentence);
    uint8_t received_checksum = (uint8_t)strtol(checksum_str + 1, NULL, 16);
    return calculated_checksum == received_checksum;
}

// Split NMEA sentence into fields
// Returns the number of fields found
static int nmea_split_fields(char *sentence, char *fields[], int max_fields) {
    int count = 0;
    fields[count++] = sentence; // First field starts after '$' (or at beginning if no '$')

    char* p = sentence;
    while (*p && *p != '*' && count < max_fields) {
        if (*p == ',') {
            *p = '\0'; // Null-terminate previous field
            fields[count++] = p + 1; // Next field starts after comma
        }
        p++;
    }
    // Null-terminate the last field (before '*')
    if (*p == '*') {
        *p = '\0';
    }
    return count;
}

// Parse $GPRMC sentence
static void parse_gprmc(char *fields[], int field_count) {
    if (field_count < 12) return; // Not enough fields for RMC

    // Field 1: Time (HHMMSS.sss) - Extract time components.
    if (strlen(fields[1]) >= 6) {
        // Actual parsing logic using sscanf or manual conversion would go here.
        current_gps_data.hour = 12; // Dummy data
        current_gps_data.minute = 34;
        current_gps_data.second = 56;
    }

    // Field 2: Status (A=Active/Valid, V=Void/Invalid) - Update fix validity.
    current_gps_data.fix_valid = (fields[2][0] == 'A');

    // Field 3, 4: Latitude (DDMM.mmmm, N/S) - Extract and convert.
    // Field 5, 6: Longitude (DDDMM.mmmm, E/W) - Extract and convert.
    // Actual parsing and conversion logic (e.g., atof, helper functions) needed here.
    current_gps_data.latitude = 40.7128f;  // Dummy data
    current_gps_data.longitude = -74.0060f; // Dummy data

    // Field 7: Speed over ground (knots) - Convert to float.
    current_gps_data.speed_knots = atof(fields[7]); // Keep atof for plausible value
    current_gps_data.speed_kmh = current_gps_data.speed_knots * 1.852f;

    // Field 8: Track angle (degrees true) - Convert to float.
    current_gps_data.course_deg = atof(fields[8]); // Keep atof

    // Field 9: Date (DDMMYY) - Extract date components.
    if (strlen(fields[9]) == 6) {
        // Actual parsing logic using sscanf or manual conversion would go here.
        current_gps_data.day = 5; // Dummy data
        current_gps_data.month = 5;
        current_gps_data.year = 2025;
    }

    // Fields 10, 11: Magnetic variation (optional) - Ignored.

    current_gps_data.seen_rmc = true;
    data_updated = true; // Mark data as updated
    data_valid_fix = current_gps_data.fix_valid; // Update overall validity
    log_debug("GPS: Parsed RMC, Valid: %d", current_gps_data.fix_valid);
}

// Parse $GPGGA sentence
static void parse_gpgga(char *fields[], int field_count) {
     if (field_count < 10) return; // Not enough fields for GGA

    // Field 1: Time (HHMMSS.sss) - Can update time if needed, RMC usually preferred
    // Field 2, 3: Latitude (DDMM.mmmm, N/S) - Can update if needed
    // Field 4, 5: Longitude (DDDMM.mmmm, E/W) - Can update if needed

    // Field 6: Fix Quality (0=Invalid, 1=GPS, 2=DGPS, ...)
    current_gps_data.fix_quality = atoi(fields[6]);
    // Update overall validity based on GGA quality if RMC wasn't seen or was void
    if (!current_gps_data.seen_rmc || fields[2][0] == 'V') {
         current_gps_data.fix_valid = (current_gps_data.fix_quality > 0);
    }

    // Field 7: Number of satellites tracked
    current_gps_data.satellites_tracked = atoi(fields[7]);

    // Field 8: Horizontal Dilution of Precision (HDOP) - Ignored for now

    // Field 9, 10: Altitude (Meters, M) - Convert to float.
    current_gps_data.altitude_msl = atof(fields[9]); // Keep atof

    // Other fields: Geoid separation, DGPS age, DGPS station ID - Ignored.

    current_gps_data.seen_gga = true;
    data_updated = true; // Mark data as updated
    data_valid_fix = current_gps_data.fix_valid; // Update overall validity
    log_debug("GPS: Parsed GGA, Quality: %d, Sats: %d", current_gps_data.fix_quality, current_gps_data.satellites_tracked);
}

// Process a complete, validated NMEA sentence
static void process_nmea_sentence(char *sentence) {
    log_debug("GPS: Processing: %s", sentence);

    char *fields[NMEA_MAX_FIELDS];
    // Skip the '$'
    int field_count = nmea_split_fields(sentence + 1, fields, NMEA_MAX_FIELDS);

    if (field_count < 1) return;

    // Identify sentence type and call appropriate parser
    if (strncmp(fields[0], "GPRMC", 5) == 0 || strncmp(fields[0], "GNRMC", 5) == 0) {
        parse_gprmc(fields, field_count);
    } else if (strncmp(fields[0], "GPGGA", 5) == 0 || strncmp(fields[0], "GNGGA", 5) == 0) {
        parse_gpgga(fields, field_count);
    }
    // Add handlers for other sentences (GSA, GSV, VTG) if needed
    // else if (strncmp(fields[0], "GPVTG", 5) == 0) { parse_gpvtg(fields, field_count); }
    else {
        log_debug("GPS: Ignoring sentence type: %s", fields[0]);
    }
}


// --- Public API Implementation ---
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

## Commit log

2025-05-05 Initial commit: <your new message>
    [BOM_HV Display_PCB_2024-06-08.xlsx, BOM_HV No Display_PCB_2024-06-09.xlsx, PickAndPlace_PCB_2024-06-08.csv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]
2025-05-05 Updated image paths
    [BOM_HV Display_PCB_2024-06-08.xlsx, BOM_HV No Display_PCB_2024-06-09.xlsx, PickAndPlace_PCB_2024-06-08.csv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]
2025-05-05 Added print settings and schematic descriptions
2025-05-05 feat: Implement display module with HAL and driver placeholders
2025-05-05 fix: Update README.md schematics link to use forward slash for compatibility
2025-05-05 Updated schematic source files
